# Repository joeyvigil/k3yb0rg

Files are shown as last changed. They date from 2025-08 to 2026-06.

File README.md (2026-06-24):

# K3YB0RG

> A 3D-printable, hand-wired mechanical keyboard inspired by the **v4n4g0n** ergo layout.

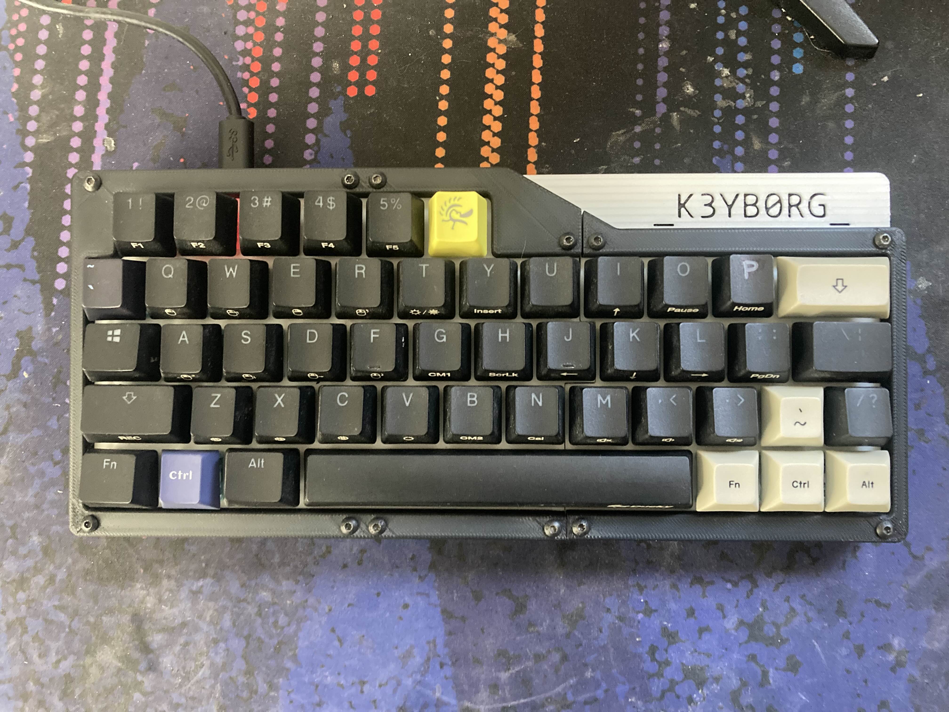
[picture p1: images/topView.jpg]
Top view of the assembled K3YB0RG keyboard


The K3YB0RG is a compact **49-key** board you print, hand-wire, and flash yourself. It runs
[QMK](https://qmk.fm/) on a Pro Micro (ATmega32U4), so the layout and layers are fully
customizable. This guide walks through every step — printing the case, wiring the switch
matrix, flashing the firmware, and final assembly.

**Build at a glance:** ~49 switches + diodes · a Pro Micro · 4 printed parts · basic soldering.
A good intermediate project — if you can solder a straight joint, you can build this.

## Contents

- [Materials](#materials)
- [3D Printing](#3d-printing)
- [Soldering & Wiring](#soldering)
- [Programming](#programming)
- [Assembly](#assembly)
- [Layers & Customization](#layers)
- [Gallery](#gallery)
- [Build Videos](#video-guide)
- [License](#license)

## Materials

**Parts**
- 1N4148 diodes — one per switch (~49)
- MX-style switches (49)
- Keycaps
- Stabilizers — 6.25u Cherry-style for the space bar
- Microcontroller — a Pro Micro with USB-C (any **ATmega32U4** board works)
- 12× **M3 × 16mm** hex screws + nuts
- 20–28 AWG **solid-core** wire (I burn the insulation off at solder points with the iron)
- USB cable (USB-C to USB-A, in my case)
- Zip ties (to secure the microcontroller)

**Tools**
- 3D printer + PLA filament
- Soldering iron (a basic one is fine — quality doesn't matter much)
- Solder — 60/40 rosin core works best
- Solder sucker

## 3D Printing

1. Download the STL files from the [`stl/`](stl) folder (or the [Releases](../../releases) page).
2. Slice with your preferred settings. I recommend:
   - 0.2mm layer height
   - 90% infill
   - a brim for bed adhesion
   - supports for the bottom parts
3. Print these four parts:
   - `V4N_bot_left.stl` (fits a wide range of microcontrollers)
   - `V4N_bot_right.stl`
   - `V4N_top_left.stl`
   - `V4N_top_right.stl`

## Soldering

### How the wiring works — read this first

The Pro Micro doesn't have one pin per key. The 49 keys are wired as a **grid of 5 rows × 12 columns**, and the controller scans that grid to detect presses — so you only run **5 + 12 = 17** signal wires, not 49.

Every switch has two legs, and you solder **three things** to them:

- **One leg → its COLUMN** — joined by a wire to every other switch in the same vertical column.
- **Other leg → a DIODE → its ROW** — solder a diode to the second leg, then join the diodes along each horizontal row.

The diode prevents *ghosting* (phantom keypresses when several keys are held at once). It only passes current one way, so **every diode must face the same direction** — on this board the **black band points toward the row**. Keep them consistent and the matrix just works.

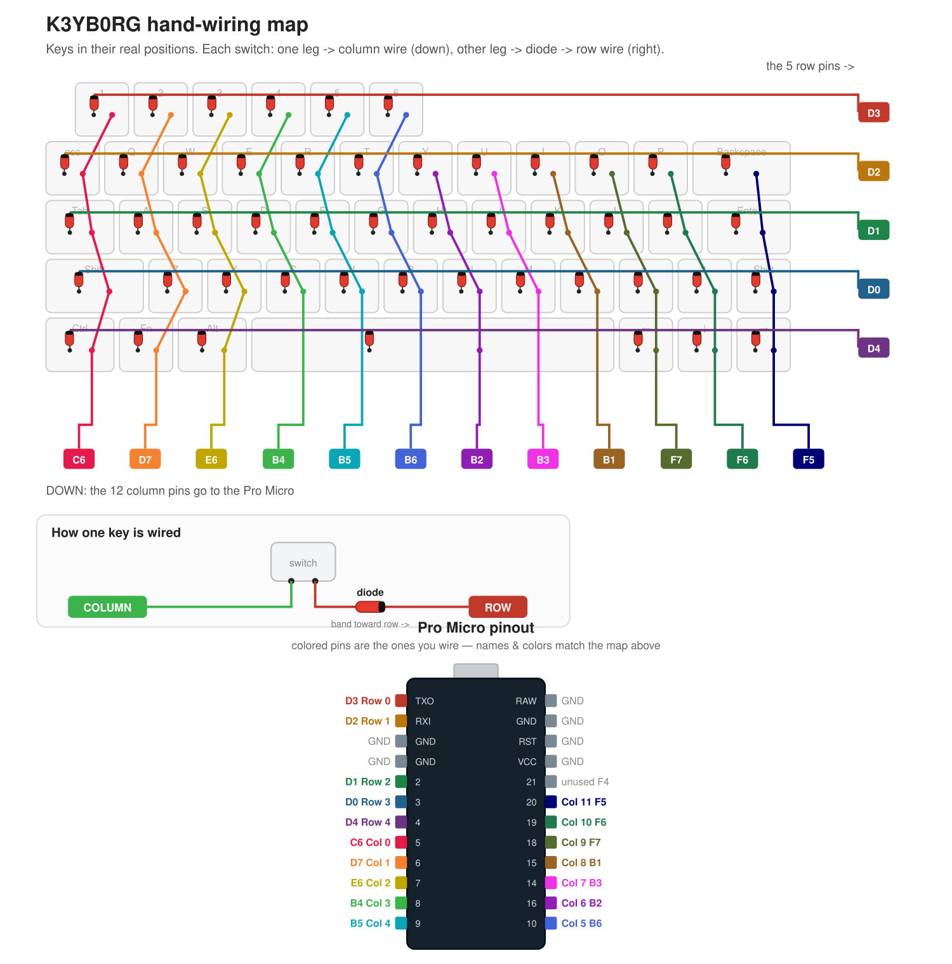
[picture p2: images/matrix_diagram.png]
Hand-wiring map: keys in real positions with color-coded row and column wires, diodes, and the Pro Micro pinout


**Where the wires land on the Pro Micro** (these come straight from `k3yb0rg.json`, so they always match the firmware):

| | Pins (in order) |
|---|---|
| **Rows** 0 → 4 (diode side) | `D3, D2, D1, D0, D4` |
| **Columns** 0 → 11 (other leg) | `C6, D7, E6, B4, B5, B6, B2, B3, B1, F7, F6, F5` |

If a key misreads after flashing, it's almost always one row/column wire on the wrong pin, or a diode soldered in backwards.

### Step 1 — Rows

1. Place all switches into the top case pieces.
2. Install the space-bar stabilizer now (you'll regret having to de-solder later if you don't).
3. Solder a diode to each switch with the **black band facing the row wire** (it points down in the photo below):
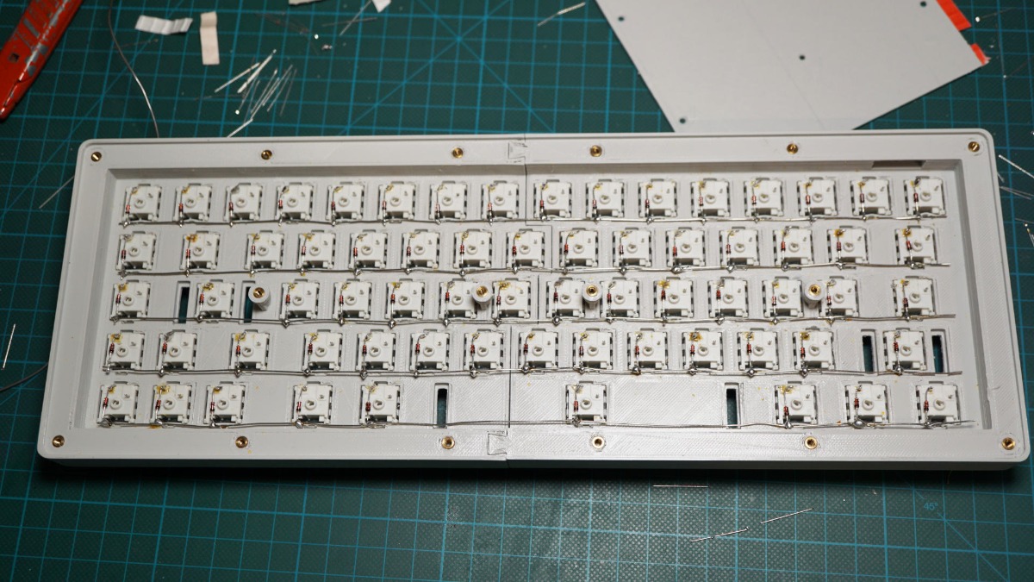
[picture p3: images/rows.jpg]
A row of switches with a diode soldered to each, black band facing the row wire
   
4. Solder a wire connecting the diodes along each row (this run goes to the microcontroller).

### Step 2 — Columns

1. Cut wire long enough to reach from each switch's other leg to the microcontroller pins.
2. Join each column down its switches as shown:
   - **Tip:** burn the insulation off the wire with the iron at each solder point.
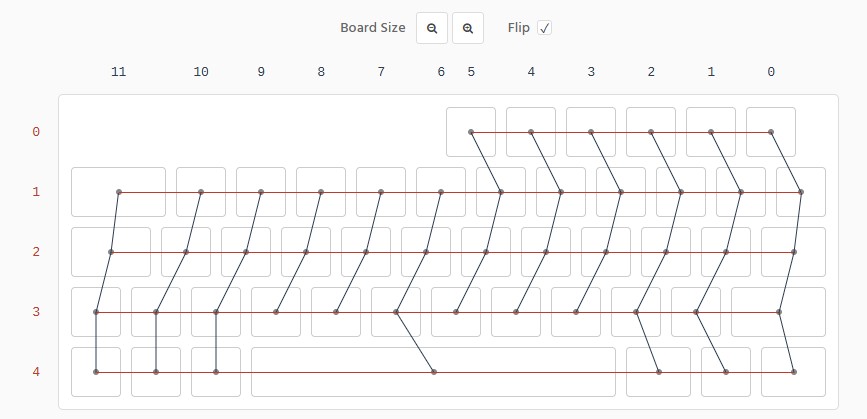
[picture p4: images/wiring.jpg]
Column wiring across the switch matrix
   

### Step 3 — Microcontroller

Solder the 17 row/column wires to the Pro Micro using the pins in the table above (and the diagram). For reference, the kbfirmware view and a Pro Micro pinout:

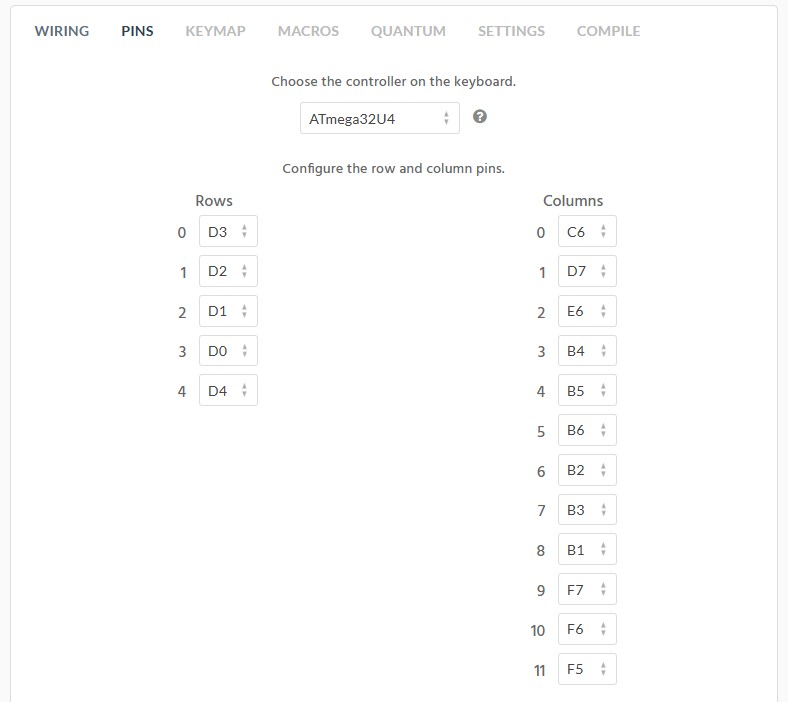
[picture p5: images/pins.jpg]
kbfirmware pin assignment

Pro Micro pinout reference


## Programming

1. Download and install [QMK Toolbox](https://qmk.fm/toolbox/).
2. Download the `k3yb0rg.hex` file from this repo.
3. Connect the microcontroller to your computer.
4. In QMK Toolbox:
   - open the hex file
   - check **Auto-flash**
   - select the right MCU (**ATmega32U4** for a Pro Micro)
   - press the reset button (or short **RST** to **GND**)
   - wait for **"Flash complete!"**
5. Your keyboard should now be functional. Open a [keyboard tester](https://www.keyboardtester.com/) to verify all keys work.
6. To customize the keymap or wiring, use [Keyboard Firmware Builder](https://kbfirmware.com/) → **Upload** → open `k3yb0rg.json`.

## Assembly

1. Place the microcontroller in the bottom-left case piece and secure it with a zip tie.
2. Join the top and bottom case pieces with the **M3 × 16mm** screws and nuts.
3. Pop on the keycaps.
4. Enjoy your new keyboard!

## Layers

Edit the layers in [Keyboard Firmware Builder](https://kbfirmware.com/) or QMK Configurator using `k3yb0rg.json`.

<table>
  <tr>
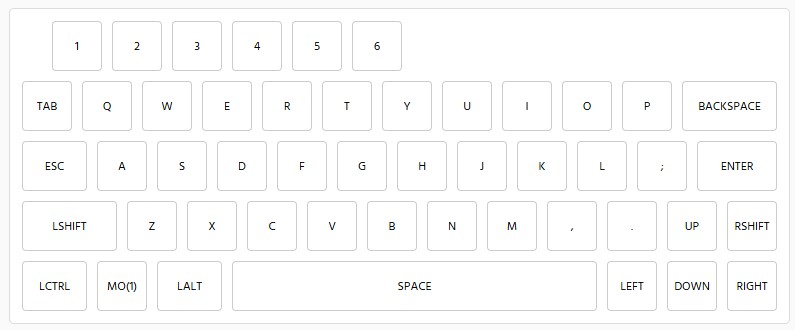
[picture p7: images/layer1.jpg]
Layer 1 keymap
    <td></td>
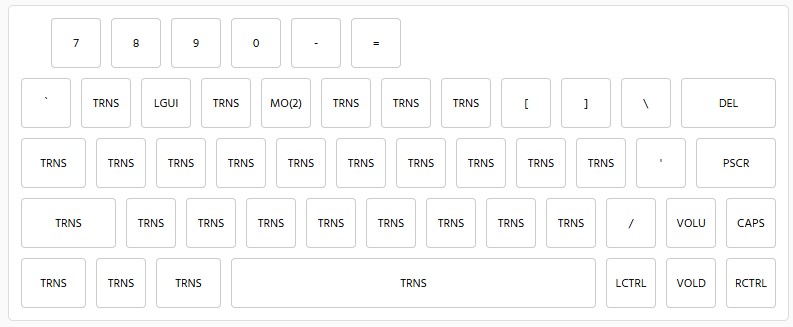
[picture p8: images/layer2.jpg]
Layer 2 keymap
    <td></td>
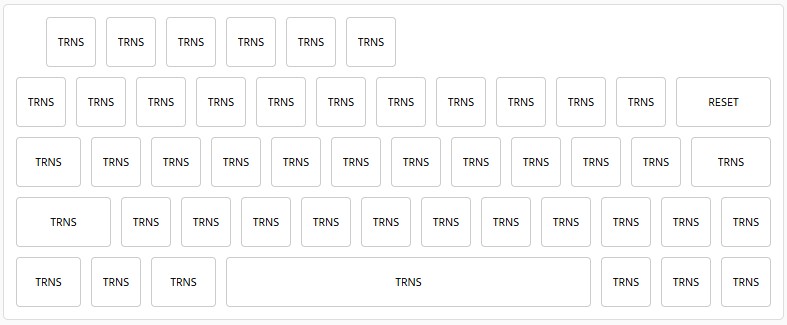
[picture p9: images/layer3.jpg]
Layer 3 keymap
    <td></td>
  </tr>
</table>

## Gallery

<table>
  <tr>
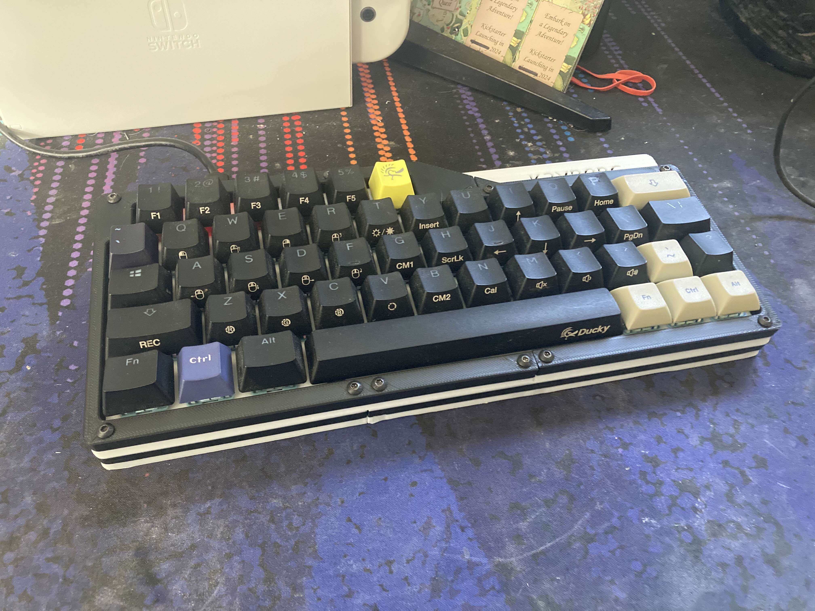
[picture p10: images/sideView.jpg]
Side view of the assembled keyboard
    <td></td>
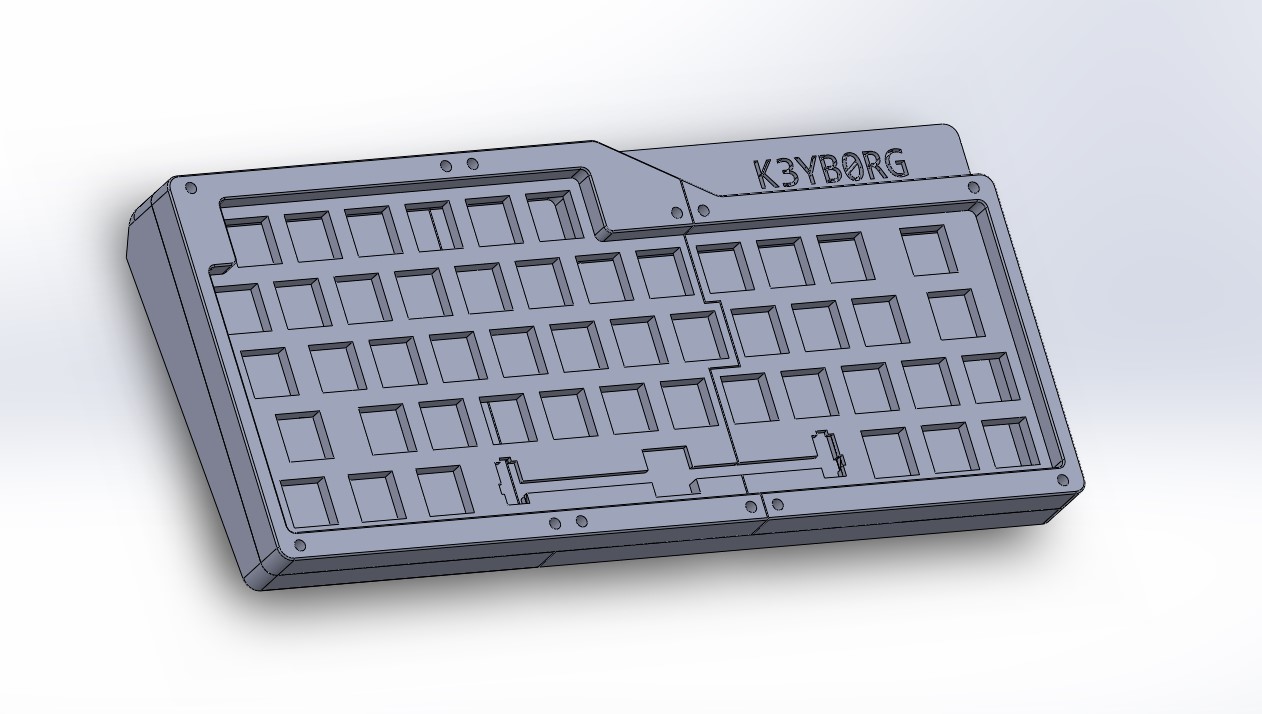
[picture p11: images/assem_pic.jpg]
Assembled keyboard
    <td></td>
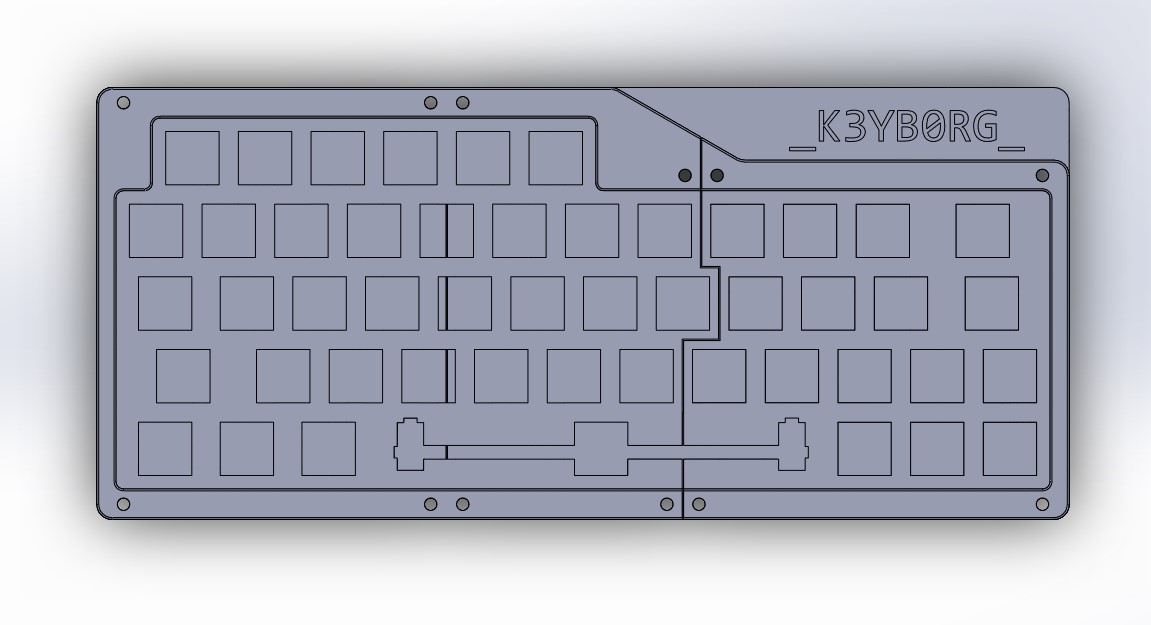
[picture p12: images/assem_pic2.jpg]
Assembled keyboard, alternate angle
    <td></td>
  </tr>
  <tr>
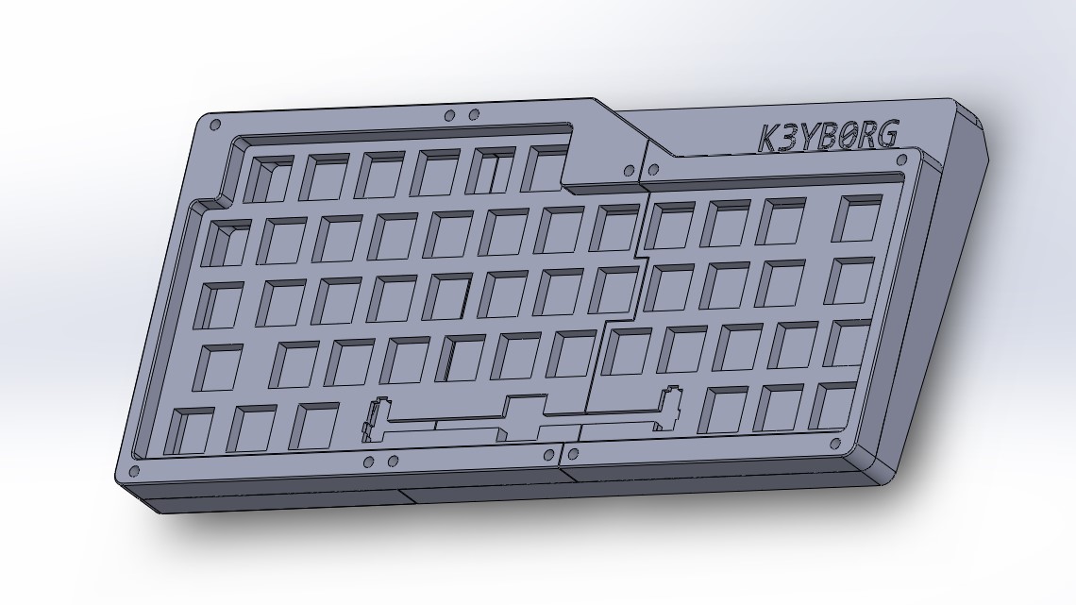
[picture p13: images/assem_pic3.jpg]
Assembled keyboard, close up
    <td></td>
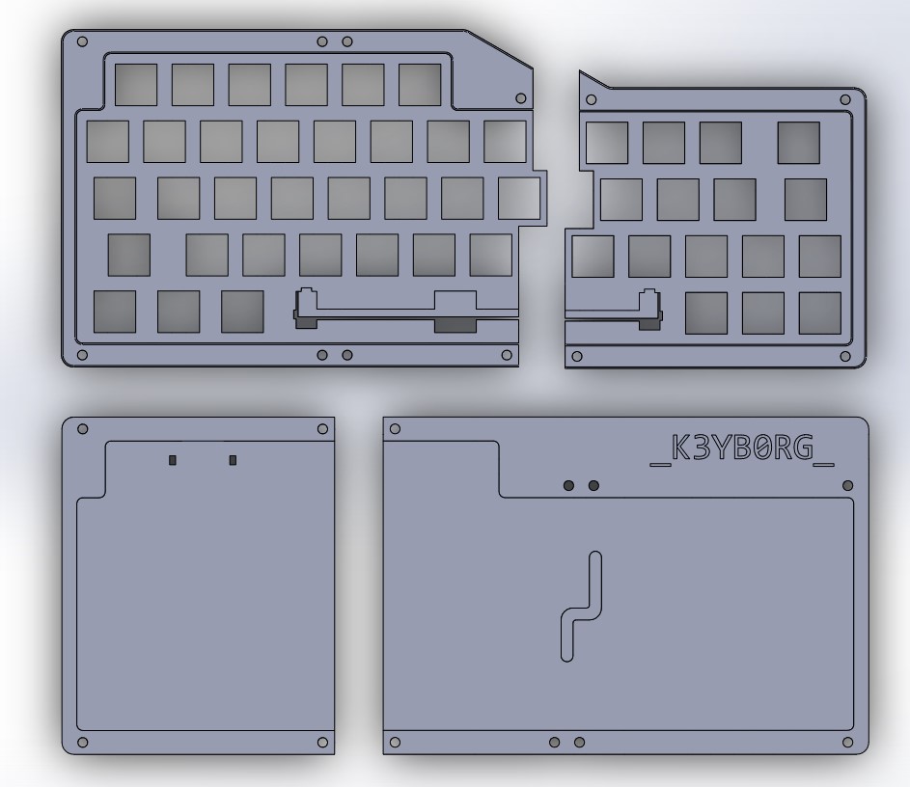
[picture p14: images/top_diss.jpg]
Top case disassembled showing the switch matrix
    <td></td>
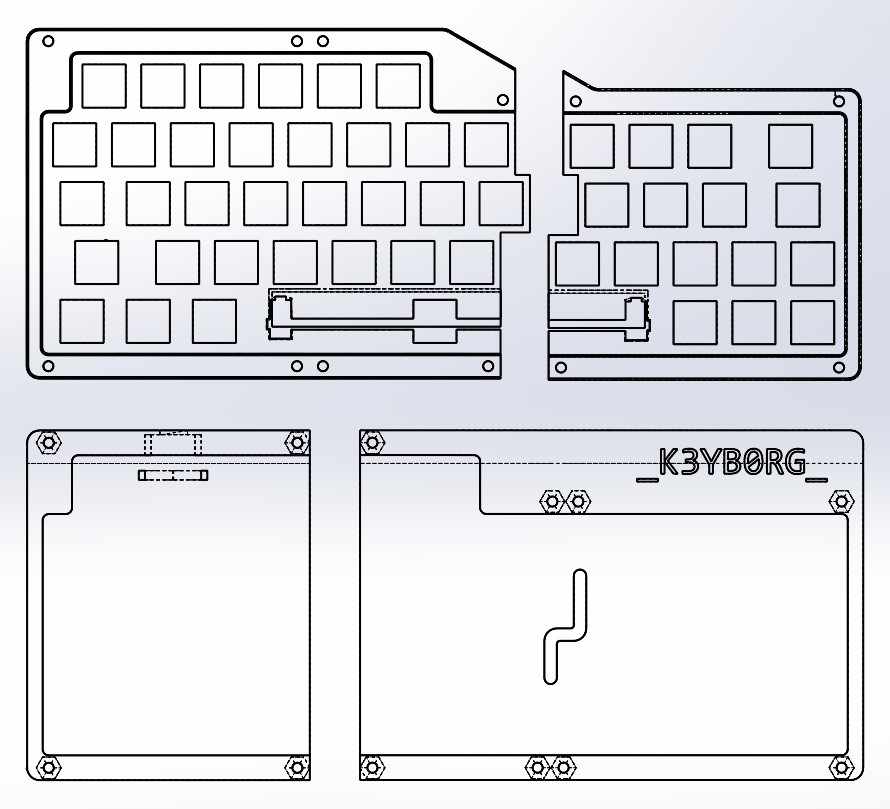
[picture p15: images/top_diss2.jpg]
Switch matrix wiring detail
    <td></td>
  </tr>
</table>

### The v4n4g0n-inspired design

<table>
  <tr>
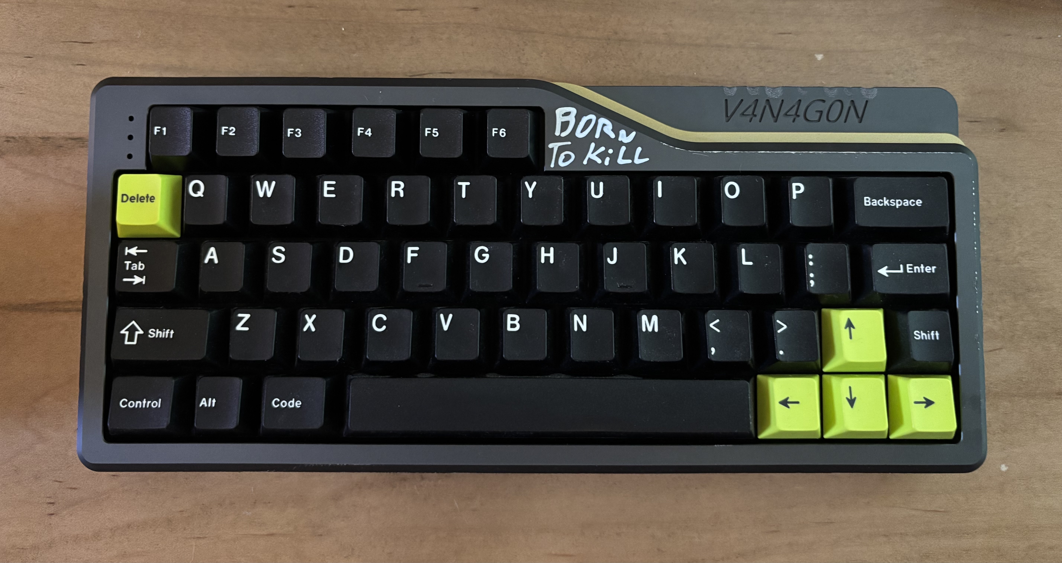
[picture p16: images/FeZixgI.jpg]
v4n4g0n keyboard that inspired this design
    <td></td>
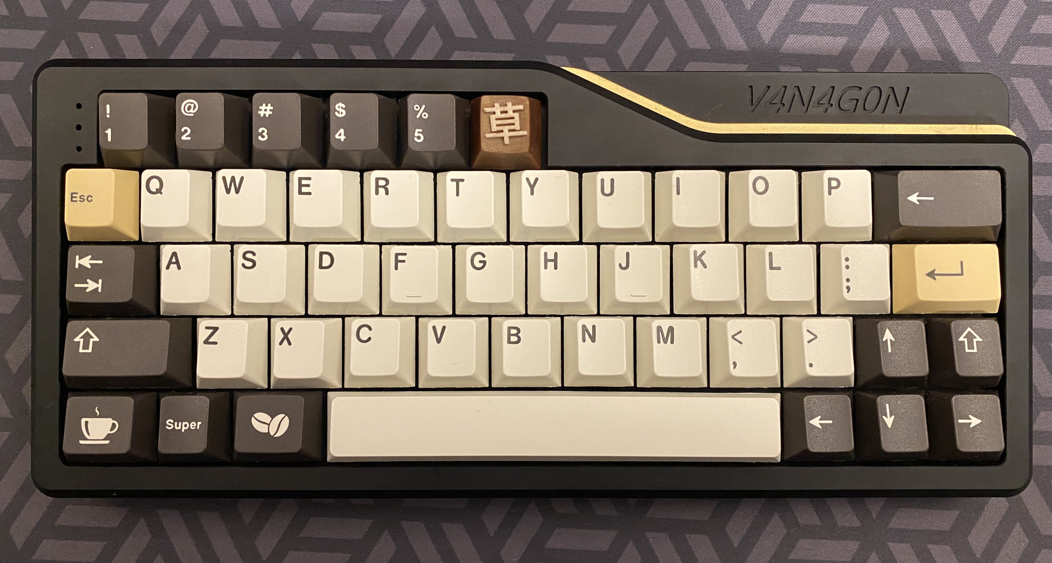
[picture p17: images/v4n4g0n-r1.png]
v4n4g0n layout reference
    <td></td>
  </tr>
</table>

## Video Guide

An older video guide I made for a previous keyboard (the process is the same):

K3YB0RG build guide video (https://www.youtube.com/watch?v=XAc28t4e77w)

**Print timelapse:**

K3YB0RG print timelapse (https://youtu.be/-jxHc12UWSU)

## License

Released under the terms in [LICENSE](LICENSE).

## Thanks

<!-- (existing thanks/credits go here) -->

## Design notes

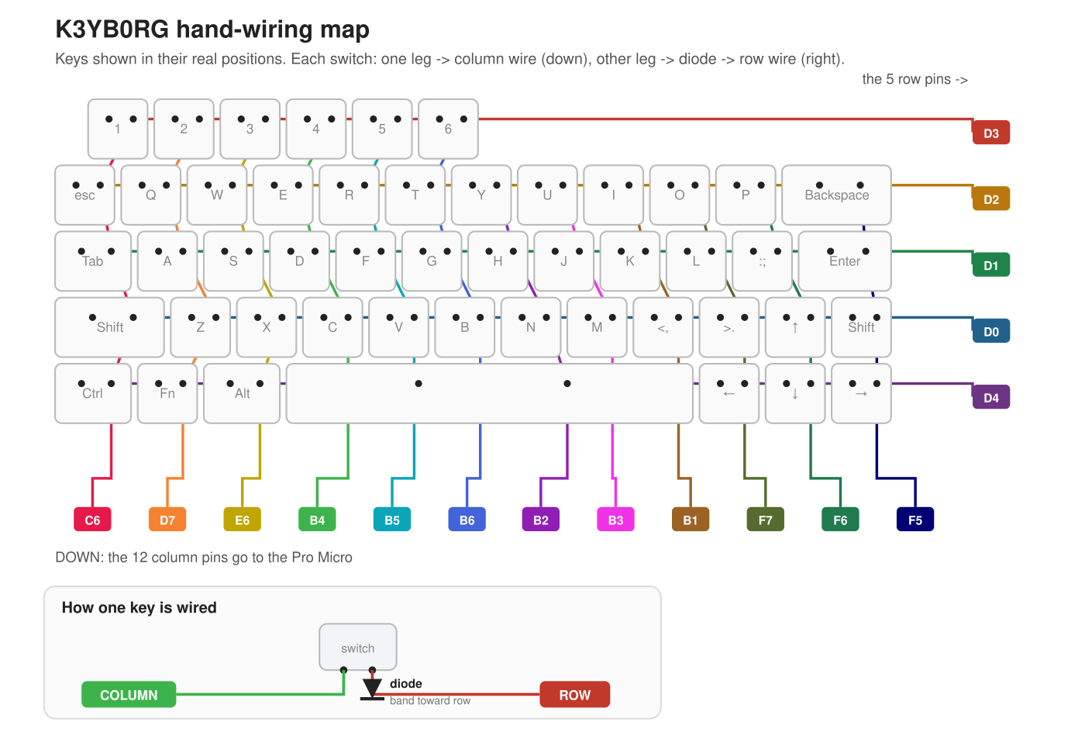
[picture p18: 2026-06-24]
images/matrix_diagram_solidkeys.png

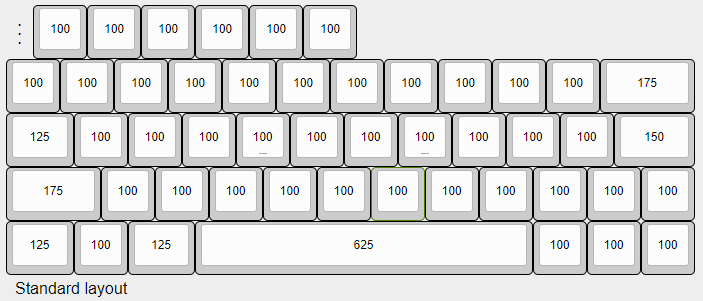
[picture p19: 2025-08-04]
images/v4n4g0n-standard.png

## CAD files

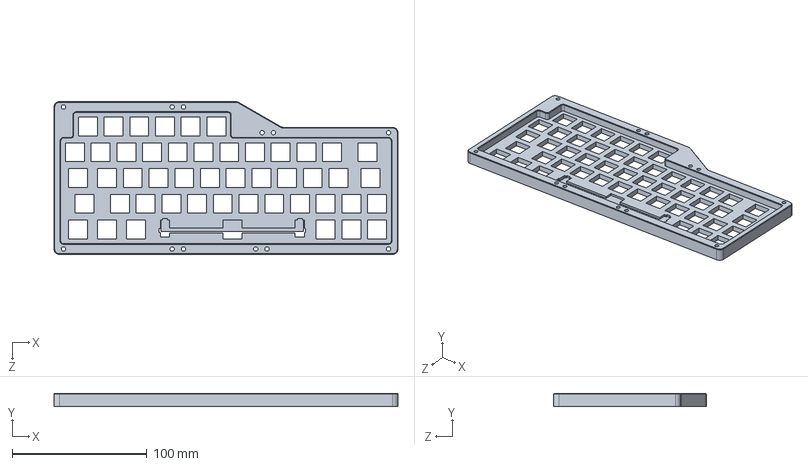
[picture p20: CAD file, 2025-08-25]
SolidWorks/V4N_top_whole.SLDPRT
254.9 x 10.0 x 113.2 mm

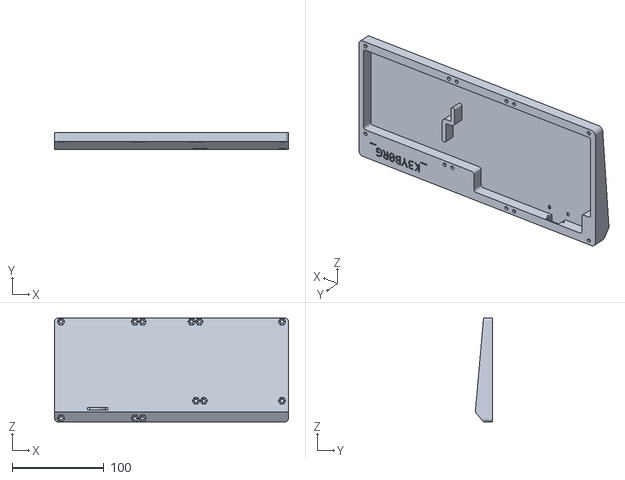
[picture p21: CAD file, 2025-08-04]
stl/V4N_bot_whole.STL
254.9 x 19.0 x 113.2

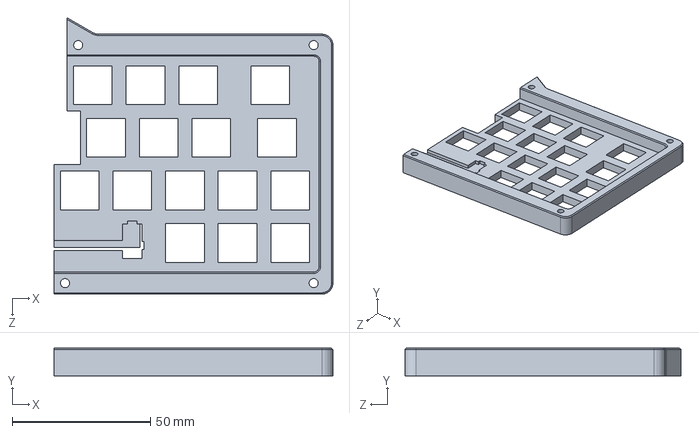
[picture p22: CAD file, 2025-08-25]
SolidWorks/V4N_top_right.SLDPRT
101.1 x 10.0 x 100.1 mm

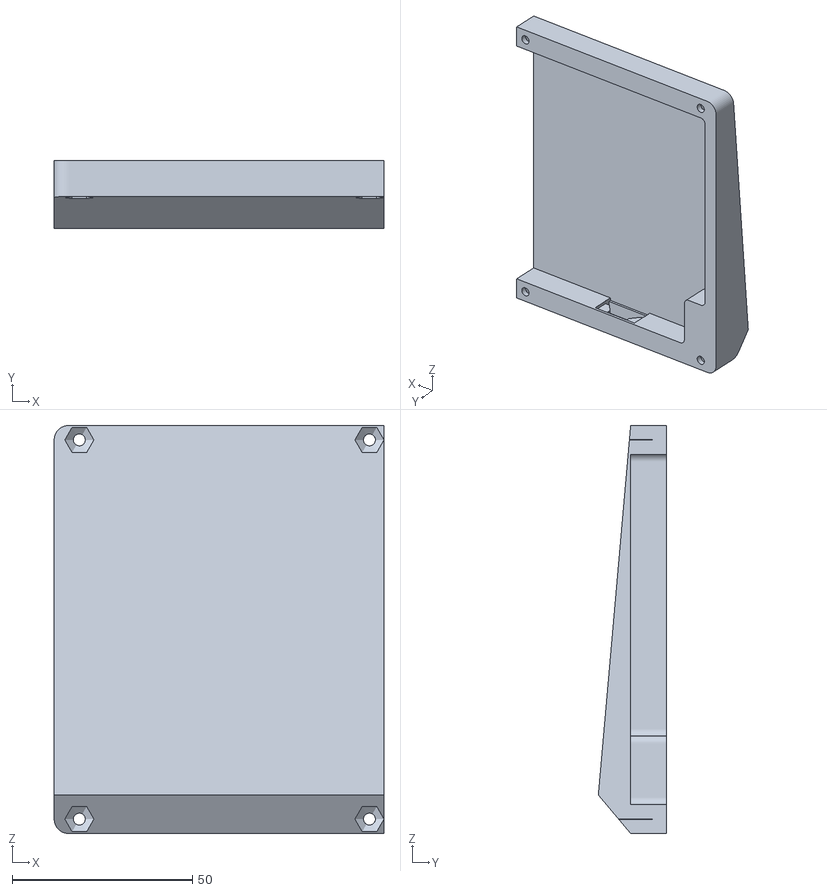
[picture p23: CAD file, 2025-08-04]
stl/V4N_bot_left_teensy.STL
91.5 x 19.0 x 113.2

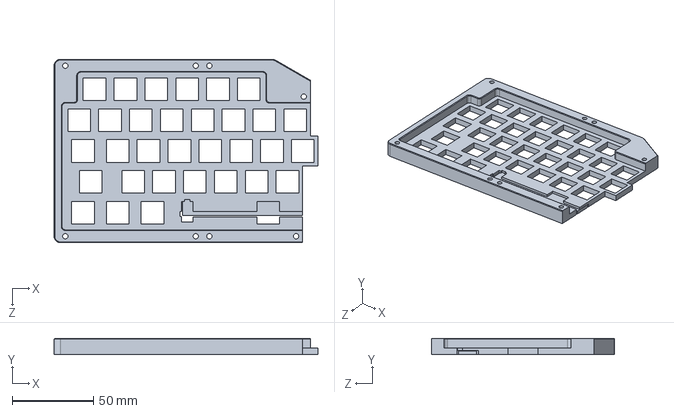
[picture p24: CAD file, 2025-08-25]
SolidWorks/V4N_top_left.SLDPRT
163.0 x 10.0 x 113.2 mm

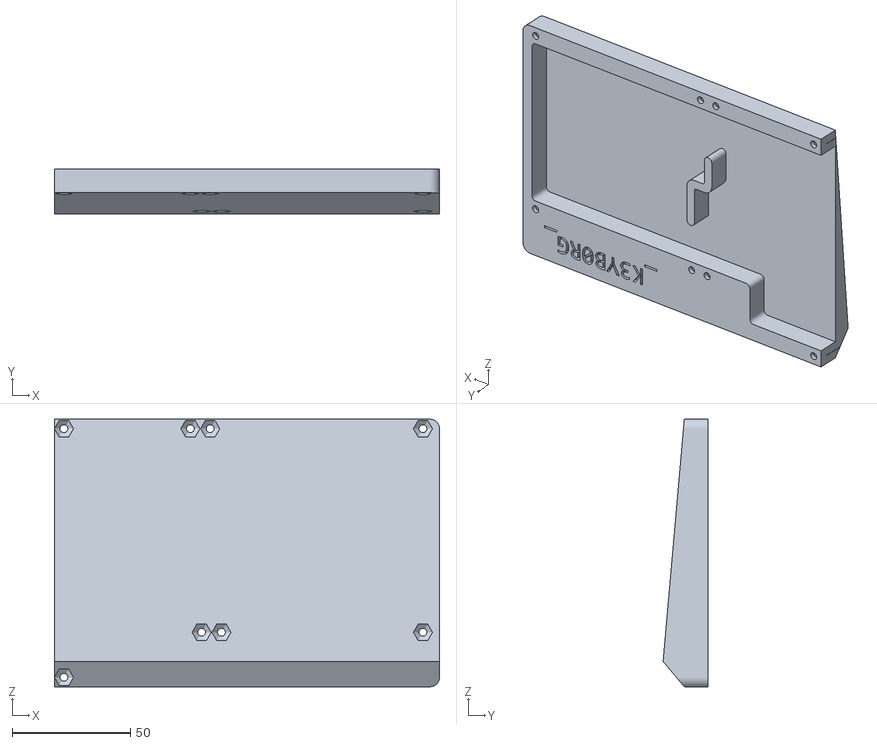
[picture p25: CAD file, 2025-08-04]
stl/V4N_bot_right.STL
163.0 x 19.0 x 113.2

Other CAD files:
stl/V4N_bot_left_pico.STL
stl/V4N_bot_left_wire.STL
stl/V4N_bot_left.STL
stl/V4N_bot_left_micro.STL
stl/V4N_top_left.STL
stl/V4N_top_right.STL
stl/V4N_top_whole.STL

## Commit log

2025-08-22 top files updated
    [V4N_top_left.SLDPRT, V4N_top_left.STL, V4N_top_right.SLDPRT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]
2025-08-25 added support
    [V4N_top_left.SLDPRT, V4N_top_left.STL, V4N_top_right.SLDPRT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]
2026-06-24 Clarify soldering: add matrix-concept explanation + clearer wiring diagram
    Addresses #1 — the original instructions jumped into the kbfirmware matrix
    view with no mental model. Adds a "how the wiring works" intro (rows/columns/
    diodes), a new two-panel diagram (single-key wiring + the full 5x12 grid with
    pin labels), and a pin table sourced from k3yb0rg.json. Includes the SVG source.
2026-06-24 Redo wiring diagram as a physical-layout map (keys in real positions)
    Replaces the abstract grid with a hand-wiring map generated from
    k3yb0rg.json: every key in its true position with its matrix row/col,
    color-coded column wires running down to their Pro Micro pins, row wires
    out to theirs, plus a "how one key is wired" inset showing diode direction.
    Matches the familiar handwired-keyboard diagram style.
2026-06-24 Wiring diagram: draw wires + diodes on top of keys so routing is visible
    Keys are now drawn light and underneath; column/row wires and a diode
    symbol per switch (band toward row) sit on top, so the wiring is no longer
    hidden behind the keycaps. Keeps the previous solid-key version as
    matrix_diagram_solidkeys.* in case we want to switch back.
2026-06-24 Wiring diagram: separate row/column attach points so they don't appear joined
    Row wire + diode now sit near the top of each key; the column wire attaches
    lower, so a column and its row only cross instead of merging at the switch
    (previously it read like pin -> diode -> row wire -> pin).
2026-06-24 Wiring diagram: add a labeled Pro Micro pinout
    Adds an accurate SparkFun Pro Micro pinout (ATmega32U4) below the wiring
    map: every pin labeled with silk number + AVR port, and the 5 row / 12
    column pins highlighted in the same colors as the map so each wire traces
    to its physical pin (e.g. C6 = silk "5", D3 = "TXO").
2026-06-24 Wiring diagram: draw diodes as red body + black band (component style)
    Replaces the schematic triangle with a physical-looking diode (red body,
    black cathode band). Band points toward the ROW wire everywhere, matching
    the board's COL2ROW diode direction (diodeDirection: 0 in k3yb0rg.json).
2026-06-24 README: quick fixes — spec, wording, and consistency
    - Fix screw spec M3 (was "3M") in materials and assembly
    - Reconcile diode wording with the new diagram (band faces the row wire)
    - Remove the now-redundant ROW 0 -> D3 "clarification" note
    - Fix typos ("bot parts", run-on in Programming step 5)
    - Tidy title and standardize headings (3D Printing, Microcontroller)
    - More descriptive image alt text on the diode photo
2026-06-24 README: restructure as a build guide (intro, TOC, gallery, license)
    - Lead with a tagline, single hero image, and a short "what it is" intro
    - Add a Table of Contents and a "build at a glance" summary
    - Split Materials into Parts vs Tools; link the stl/ folder + Releases
    - Number the soldering as Step 1/2/3; new diagram is the primary reference
    - Move the stack of top photos into a Gallery section at the bottom
    - Put layer/gallery images in tables with descriptive alt text
    - Add a License section linking LICENSE
